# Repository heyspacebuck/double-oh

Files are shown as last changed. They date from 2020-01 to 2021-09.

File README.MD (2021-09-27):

# Double-Oh Battery

## Hardware version 2.7, Firmware version 1.0

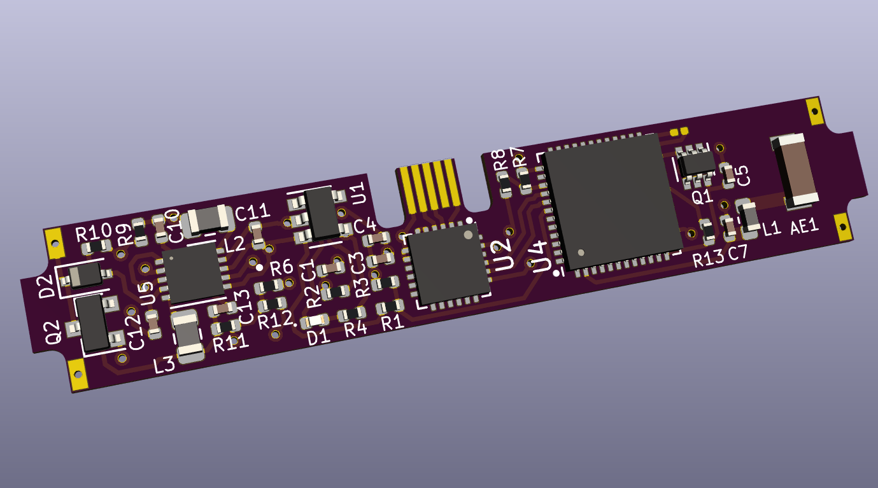
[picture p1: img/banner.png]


This is the spiritual successor to the [SMOL](https://github.com/heyspacebuck/SMOL), a tiny PCB that interrupts battery output to make fun patterns. By designing around a 10mm-by-44mm LiPo cell, I've been able to add Wi-Fi connectivity, a USB connection for charging and programming, and a dangerous (but intriguing!) overvoltage mode.

The star of the show is the ESP32-PICO-D4, a 7mm-by-7mm powerhouse. It handles the wireless networking and various GPIOs.

Hardware developed in KiCad 5.1; firmware built in the Arduino IDE. Licensed/Licenced with the [CERN OHL](https://www.ohwr.org/project/cernohl/wikis/home). Documentation covered by [Creative Commons Attribution (CC-BY) 4.0](https://creativecommons.org/licenses/by/4.0/).

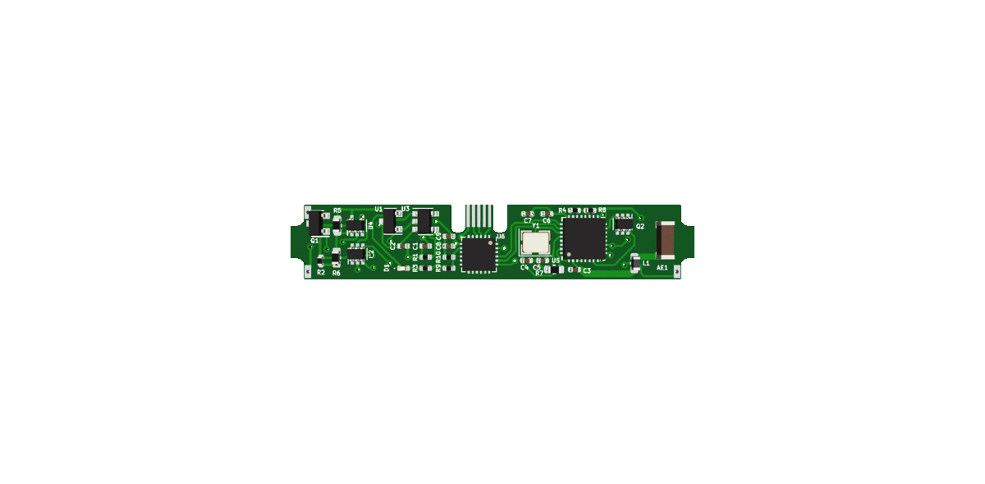
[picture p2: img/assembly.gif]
Small assembly animation


## Assembly, setup, installation

Bill of materials is [here](bom.md). An interactive HTML BOM is [here](/hardware/bom/ibom.html). Assembly and initial setup is covered [here](setup.md).

## Schematic

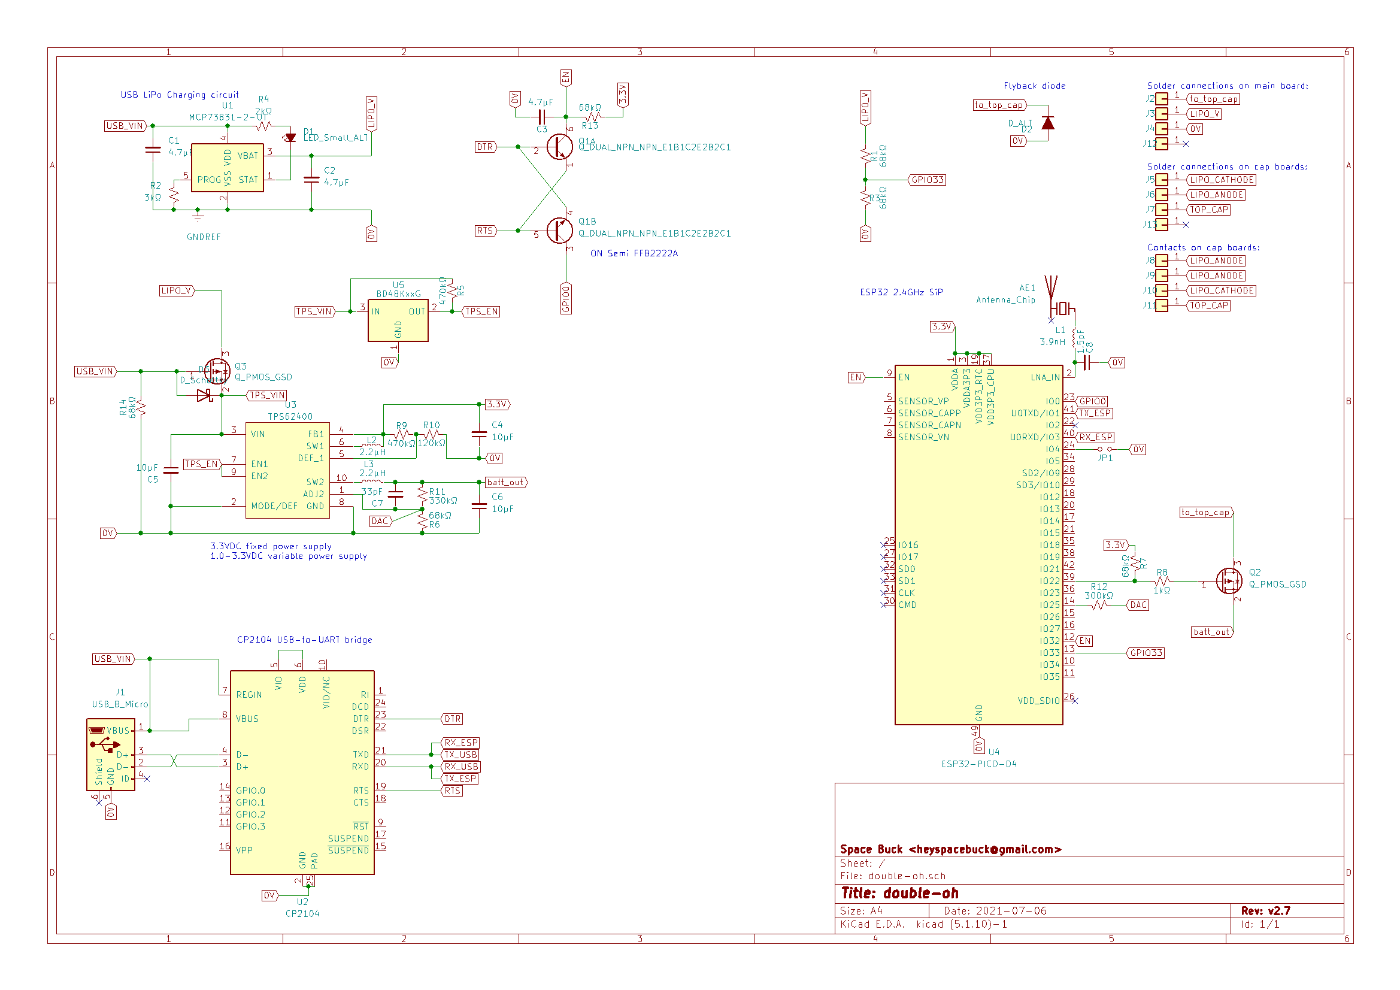
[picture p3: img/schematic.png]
schematic


[A pdf version is also available.](/img/schematic.pdf)

## To do:

* Add pictures to [setup/assembly instructions](setup.md)
* Improve the user interface
* Generate renders



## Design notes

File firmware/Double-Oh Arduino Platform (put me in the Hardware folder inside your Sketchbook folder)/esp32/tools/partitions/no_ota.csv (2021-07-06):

# Name | Type | SubType | Offset | Size | Flags
nvs | data | nvs | 0x9000 | 0x5000
otadata | data | ota | 0xe000 | 0x2000
app0 | app | ota_0 | 0x10000 | 0x200000
spiffs | data | spiffs | 0x210000 | 0x1F0000

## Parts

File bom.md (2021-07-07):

# Bill of Materials
## Valid as of Hardware version 2.7

See also: [interactive HTML BOM](/hardware/bom/ibom.html)

| |References |Value |Footprint |Quantity|Notes |
|---|---|---|---|---|---|
|1 |C1, C2, C3 |4.7μF |0402 (1005 Metric)  |2 | |
|2 |C4, C5, C6 |10μF |0402 (1005 Metric)  |3 | |
|3 |C7 |33pF |0402 (1005 Metric)  |1 | |
|4 |C8 |1.5pF |0402 (1005 Metric)  |1 | |
|5 |R1, R3, R6, R7, R13, R14|68kΩ |0402 (1005 Metric)  |6 | |
|6 |R2 |3kΩ |0402 (1005 Metric)  |1 | |
|7 |R4 |2kΩ |0402 (1005 Metric)  |1 | |
|8 |R5, R9 |470kΩ |0402 (1005 Metric)  |1 | |
|9 |R8 |1kΩ |0402 (1005 Metric)  |1 | |
|10 |R10 |120kΩ |0402 (1005 Metric)  |1 | |
|11 |R11 |330kΩ |0402 (1005 Metric)  |1 | |
|12 |R12 |300kΩ |0402 (1005 Metric)  |1 | |
|13 |L1 |3.9nH |0603 (1608 Metric)  |1 | |
|14 |L2, L3 |2.2μH |0806 (2016 Metric)  |2 |Should be rated for at least 800 mA|
|15 |D1 |LED Blue |0402 (1005 Metric)  |1 | |
|16 |D2, D3 |Schottky Diode |0402 (1005 Metric)  |2 | |
|17 |U1 |MCP73831-2-OT  |SOT-23-5 |1 |USB Li-ion charging controller |
|18 |U2 |CP2104 |QFN-24 4x4mm P0.5mm |1 |USB-to-UART bridge |
|19 |U3 |TPS62400 |VSON-10 3x3mm P0.5mm|1 |Dual-output voltage regulator |
|20 |U4 |ESP32-PICO-D4  |QFN-48 7x7mm P0.5mm |1 |The brains of the operation |
|21 |U5 |BD48K34G |SOT-23 |1 |Low-battery power supervisor; on back of board  |
|22 |AE1 |AMCA31 |1206 (3216 Metric)  |1 |2.4 GHz chip antenna |
|23 |Q1 |BC847BS |SOT-363 (SC-88) |1 |Dual NPN transistors |
|24 |Q2, Q3 |NTS4101P |SOT-323 (SC-70) |2 |P-Channel MOSFET |

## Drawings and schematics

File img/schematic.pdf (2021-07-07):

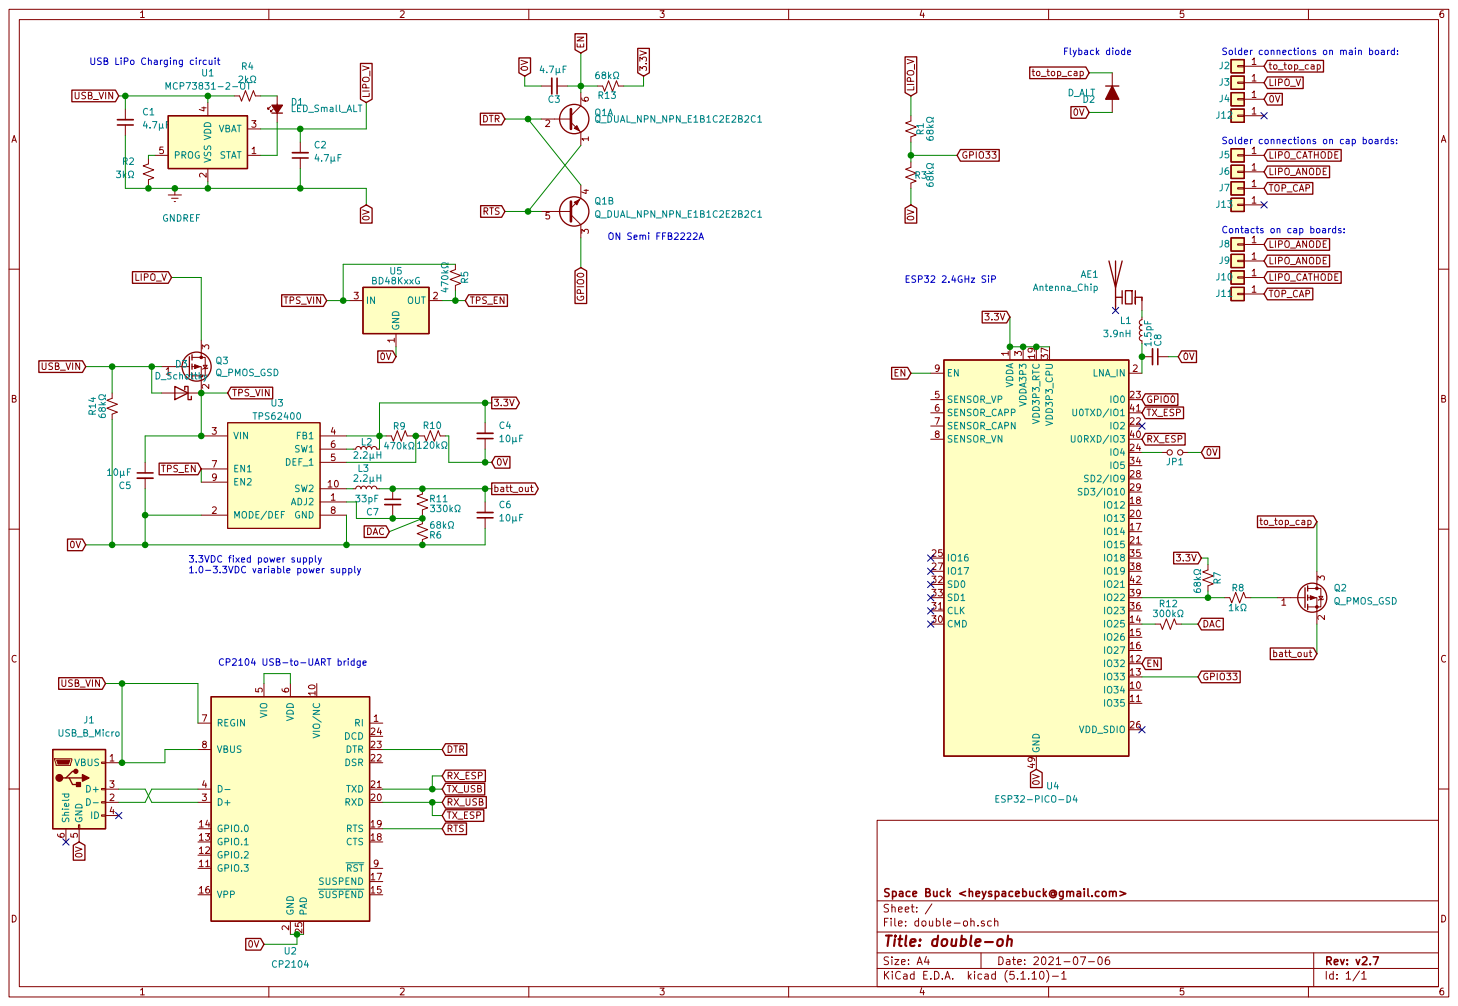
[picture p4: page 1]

USB LiPo Charging circuit

Contacts on cap boards:

CP2104 USB-to-UART bridge

2 RXD 20 TXD 21 DSR 22 DTR 23 DCD 24 PAD 25 D+ 3 D- 4 VIO

File: double-oh.sch Sheet: / Space Buck <heyspacebuck@gmail.com>

Id: 1/1 Title: double-oh

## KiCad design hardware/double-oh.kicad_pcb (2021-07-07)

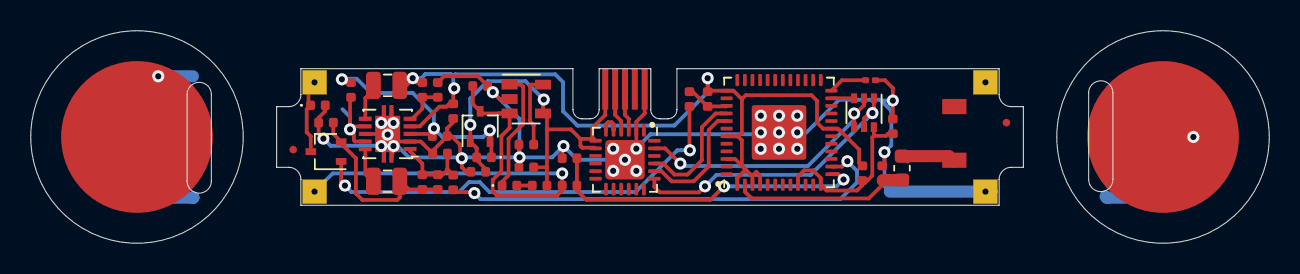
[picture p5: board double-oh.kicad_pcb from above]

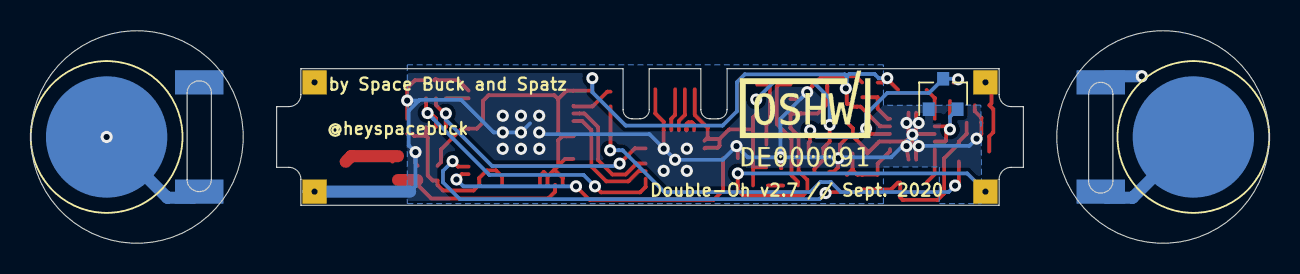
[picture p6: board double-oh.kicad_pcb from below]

Board: 2 copper layers, 81.6 x 14.0 mm, 51 parts (7 on the bottom side), 34 nets.

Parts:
AE1: Antenna_Chip; AMCA31
C1, C2, C3: 4.7μF; C_0402_1005Metric
C4, C5, C6: 10μF; C_0402_1005Metric
C7: 33pF; C_0402_1005Metric
C8: 1.5pF; C_0402_1005Metric
D1: LED_Small_ALT; LED_0402_1005Metric
D2: D_ALT; D_0402_1005Metric
D3: D_Schottky; D_0402_1005Metric
J1: USB_B_Micro; microusb_PCB_socket
J2, J3, J4, J12: Conn_01x01; main_board_solder_mount
J5, J6, J7, J13: Conn_01x01; cap_board_solder_mount
J8, J11: Conn_01x01; cap_contact
J9, J10: Conn_01x01; lipo_contact
JP1: Jumper_NO_Small; R_0201_0603Metric
L1: 3.9nH; L_0603_1608Metric
L2, L3: 2.2μH; L_0806_2016Metric
Q1: Q_DUAL_NPN_NPN_E1B1C2E2B2C1; SOT-363_SC-70-6
Q2, Q3: Q_PMOS_GSD; SOT-323_SC-70
R1, R3, R6, R7, R13, R14: 68kΩ; R_0402_1005Metric
R2: 3kΩ; R_0402_1005Metric
R4: 2kΩ; R_0402_1005Metric
R5, R9: 470kΩ; R_0402_1005Metric
R8: 1kΩ; R_0402_1005Metric
R10: 120kΩ; R_0402_1005Metric
R11: 330kΩ; R_0402_1005Metric
R12: 300kΩ; R_0402_1005Metric
U1: MCP73831-2-OT; SOT-23-5
U2: CP2104; QFN-24-1EP_4x4mm_P0.5mm_EP2.6x2.6mm
U3: TPS62400; VSON-10-1EP_3x3mm_P0.5mm_EP1.65x2.4mm
U4: ESP32-PICO-D4; QFN-48-1EP_7x7mm_P0.5mm_EP3.6x3.6mm
U5: BD48KxxG; SOT-23

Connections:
0V: C1.1, C2.1, C3.2, C4.1, C5.2, C6.1, C8.1, D2.2, J1.5, J4.1, JP1.1, R2.1, R3.2, R6.2, R10.1, R14.1, U1.2, U2.2, U2.25, U3.2, U3.8, U3.11, U4.49, U5.1
3.3V: C4.2, L2.2, R7.1, R9.1, R13.1, U3.4, U4.1, U4.3, U4.4, U4.19, U4.37, U4.43, U4.46
DAC: C7.2, R6.1, R11.2, R12.1, U3.1
DTR: Q1.2, Q1.4, U2.23
EN: C3.1, Q1.6, R13.2, U4.9, U4.12
GPIO0: Q1.3, U4.23
GPIO33: R1.2, R3.1, U4.13
LIPO_ANODE: J6.1, J8.1, J9.1
LIPO_CATHODE: J5.1, J10.1
LIPO_V: C2.2, J3.1, Q3.3, R1.1, U1.3
unnamed: AE1.1, L1.1
unnamed: C8.2, L1.2, U4.2
unnamed: D1.1, U1.1
unnamed: D1.2, R4.2
unnamed: J1.2, U2.4
unnamed: J1.3, U2.3
unnamed: JP1.2, U4.24
unnamed: L2.1, U3.6
unnamed: L3.1, U3.10
unnamed: Q2.1, R8.2
unnamed: R2.2, U1.5
unnamed: R7.2, R8.1, U4.39
unnamed: R9.2, R10.2, U3.5
unnamed: R12.2, U4.14
unnamed: U2.5, U2.6
RTS: Q1.1, Q1.5, U2.19
RX_ESP: U2.21, U4.40
RX_USB: U2.20, U4.41
TOP_CAP: J7.1, J11.1
TPS_EN: R5.2, U3.7, U3.9, U5.2
TPS_VIN: C5.1, D3.1, Q3.2, R5.1, U3.3, U5.3
USB_VIN: C1.2, D3.2, J1.1, Q3.1, R4.1, R14.2, U1.4, U2.7, U2.8
batt_out: C6.2, C7.1, L3.2, Q2.2, R11.1
to_top_cap: D2.1, J2.1, Q2.3

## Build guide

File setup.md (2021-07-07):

# Double-Oh Battery Assembly and Setup

## Hardware version 2.7, Firmware version 1.0



## Main PCB: Top side assembly

Parts used:
- 35 SMD components (see the [BOM](bom.md))
- Main PCB

All but one of the Double-Oh components are placed on the top side of the PCB. When this side is assembled, we can run the device off USB power and install the Double-Oh firmware. The [interactive BOM](/hardware/bom/ibom.html) makes placing the components a lot easier.

## Firmware installation

Tools used:
- Micro-USB cable
- Arduino IDE
- Multimeter (optional)

Now that the top side of the PCB is assembled, the Double-Oh firmware can be installed. Plug in the micro-USB cable and do a quick "smoke test," that is, make sure none of your components are overheating. If everything feels okay, proceed to the Arduino IDE.

If you haven't already, configure the Arduino IDE to work with ESP32 boards. In the "Preferences" window, add the following URL to the "Additional Boards Manager URLs" section: `https://dl.espressif.com/dl/package_esp32_index.json`. Go to `Tools > Board > Boards Manager` and install the "ESP32 by Espressif Systems" boards. A more thorough tutorial [is available here](https://randomnerdtutorials.com/installing-the-esp32-board-in-arduino-ide-windows-instructions/).

To select the Double-Oh board in the Arduino IDE, take the folder `/firmware/Double-Oh Arduino Platform` out of this repo and copy it into your Arduino sketchbook's "Hardware" folder. The folder's new location should be `{your Arduino sketchbook directory}/Hardware/Double-Oh Arduino Platform`. Restart the Arduino IDE. Now, you should be able to select the Double-Oh board under `Tools > Board > Double-Oh > Double-Oh`. **ALTERNATELY:** you can use the "ESP32 Dev Module" from Espressif's boards. If you do this ***make sure PSRAM is disabled!*** As of writing this (July 2021), enabling PSRAM will cause an endless kernel panic reboot cycle, effectively bricking the ESP32.

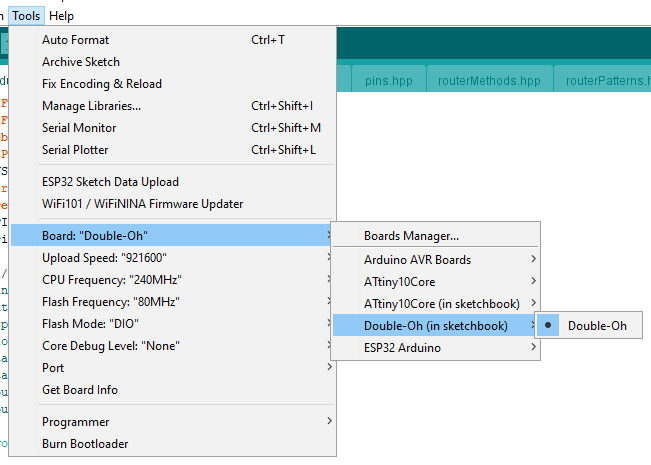
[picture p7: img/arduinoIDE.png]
Screenshot of the Arduino IDE


Open the Double-Oh firmware sketch, located at `/firmware/firmware.ino`. Check that the ESP32 shows up under `Tools > Port` and select it. Upload the file system image by clicking `Tools > ESP32 Sketch Data Upload`. Then upload the firmware with the normal "Upload" button.

**Troubleshooting:** I've encountered several possible errors at this stage, mostly stemming from bad soldering on U2, U3, and U4. If the USB device is not recognized by your computer, that's probably an issue with U2, the USB-to-UART bridge IC. Check that U3 is putting out at least 3.0 volts to power the ESP32; you can do this by probing the locations shown here:

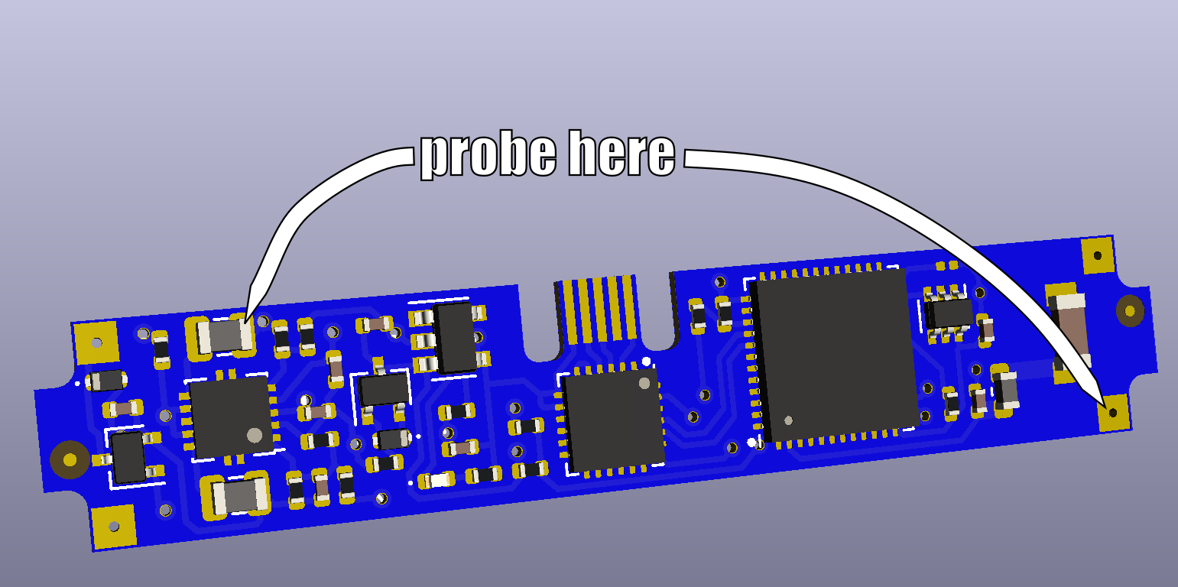
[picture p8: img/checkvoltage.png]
Showing which two points to probe for voltage measurements


If you receive a "Timed out waiting for packet header" message, that typically means either U3 or U4 is soldered incorrectly; often, I have found the ESP32 is not fully soldered to the pads. If you receive an "Incorrect packet header" message, it could mean that the RTS signal is too noisy; you can try increasing the capacitance of C3, the capacitor next to the dual-NPN transistor package.

## Network Testing

When the firmware is first uploaded, the board should start broadcasting its own Wi-Fi network called "double-oh". Connect to the Wi-Fi network and navigate to `http://doubleoh.local` . You should see a simple HTML page with Double-Oh network settings that can be customized.

## Finishing assembly

Parts used:
- U5 (the only component on the bottom of the PCB)
- Cathode (red) PCB
- Anode (black) PCB
- Something to keep the battery in place--a short length of stiff wire, or a [battery terminal spring](https://www.digikey.com/en/products/detail/keystone-electronics/242/7561622), or an [EMI shield finger](https://www.digikey.com/en/products/detail/harwin-inc/S7081-42R/3131061)

Solder part U5, the SOT-23 voltage supervisor, on the bottom side of the PCB. This enables the device to run off a 10440 Li-ion cell.

Take the anode (black) PCB and solder a spring or wire or something to the inner face (the side with a smaller circle on it). This is the part of assembly that I really haven't solved yet. A stiff wire works well, most of the time. Sometimes a single 1.5mm spring suffices; sometimes I have to solder a second 1.5mm spring onto the cathode (red) PCB as well. It's a bit of a mess.

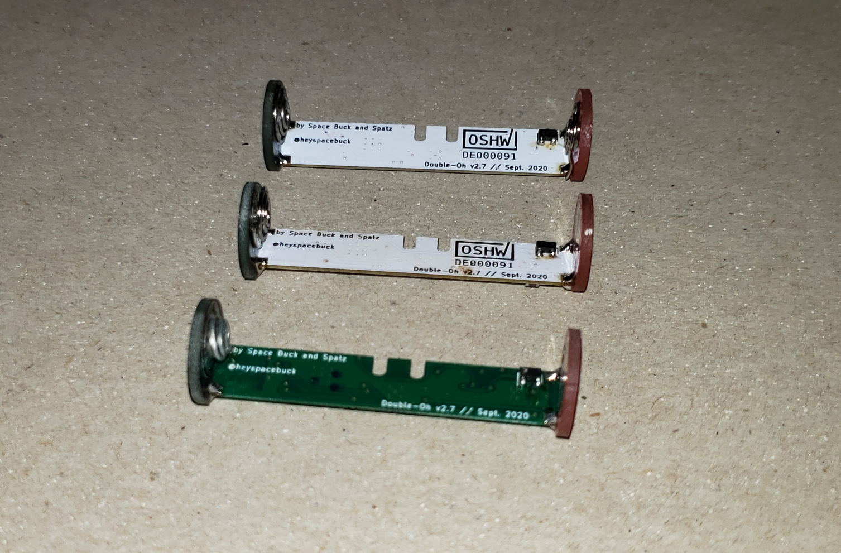
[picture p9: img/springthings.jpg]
Different boards with different spring options


Carefully line up the main PCB in the slot of the anode (black) PCB; the antenna should be close to the black PCB and facing outward. Tack-solder one joint and check the boards for alignment. When the main board and anode board are aligned, . Then do the same with the cathode (red) PCB.

## Battery testing

Parts used:
- 10440 Li-ion cell

Install the Li-ion cell inside the Double-Oh and check again for the "double-oh" Wi-Fi network.

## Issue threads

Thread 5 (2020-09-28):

Silk over vias

silardg, 2020-09-28:
First of all, big fan!

I noticed that the silk (example U2) is over a VIA, which won't look good when manufactured.

heyspacebuck, 2020-09-29:
Thank you for your attention to detail! I have noticed this as well, but until now I had considered it just a minor nuisance. The image at the top of the readme is *very* outdated, since then I have removed all the references from the top of the board; the only remaining silks are on the back of the board and I think they are all legible despite the presence of vias. Again, thanks for writing!

Closed 2020-09-29.

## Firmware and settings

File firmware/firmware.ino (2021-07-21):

#include <WiFi.h>
#include <WiFiClient.h>
#include <WebServer.h>
#include <ESPmDNS.h>
#include <DNSServer.h>
#include <Wire.h>
#include <Preferences.h>
#include <SPIFFS.h>
#include <driver/dac.h>

// From the /include/ folder (the order they're included in here matters!)
#include "pins.hpp"
#include "battery.hpp"
#include "eepromInit.hpp"
#include "globals.hpp"
#include "startEeprom.hpp"
#include "station.hpp"
#include "routerMethods.hpp"
#include "routerPatterns.hpp"

void setup(void) {
  // Set the FET output HIGH (i.e. turn output off)
  ledcSetup(0, 1000, 8);
  ledcAttachPin(OUTPUT_PIN, 0);
  ledcWrite(0, 255);

  // Begin serial link at 115200 baud
  Serial.begin(115200);

  // Check if the factory-reset pads are shorted:
  // Set factory-reset pin to input_pullup
  pinMode(FACTORY_RESET_PIN, INPUT_PULLUP);
  bool factoryReset = false;
  if (!digitalRead(FACTORY_RESET_PIN)) {
    factoryReset = true;
    Serial.println("Factory Reset");
  } else {
    Serial.println("No factory reset");
  }

  // Set DAC voltage test for GPIO 25 (DAC channel 1)
  // Approx 12.126 mV per bit
  dac_output_enable(DAC_CHANNEL_1);
  setBatteryLevel(1.50);
//  dac_output_voltage(DAC_CHANNEL_1, 128); // 2.60 V
//  dac_output_voltage(DAC_CHANNEL_1, 160); // 2.21 V
//  dac_output_voltage(DAC_CHANNEL_1, 180); // 1.97 V
//  dac_output_voltage(DAC_CHANNEL_1, 200); // 1.73 V
//  dac_output_voltage(DAC_CHANNEL_1, 210); // 1.60 V
//  dac_output_voltage(DAC_CHANNEL_1, 220); // 1.49 V
//  dac_output_voltage(DAC_CHANNEL_1, 230); // 1.36 V
//  dac_output_voltage(DAC_CHANNEL_1, 240); // 1.24 V
//  dac_output_voltage(DAC_CHANNEL_1, 255); // 1.06 V

  // Turn on file system
  SPIFFS.begin();

  // Turn on EEPROM, read data, perform a factory reset if the factory-reset pins are shorted
  startEEPROM(factoryReset);

  // If byte 0 is 0x00, set up a soft access point; else set up station
  if (eeprom.wifiType == 0x00) {
    Serial.println("Starting Soft AP");
    startSoftAP();
    // startSoftAP(eeprom.deviceName, dnsServer, DNS_PORT);
  } else {
    Serial.println("Connecting to Wi-Fi");
    // startStation(eeprom, dnsServer, DNS_PORT);
    startStation();
  }


  // On a GET request to /, serve the control panel
  server.on("/", HTTP_GET, handleRoot);

  // On POST request to /settings, change the Wi-Fi configuration
  server.on("/settings", HTTP_POST, handleSettingsPost);

  // On POST request to /power, change the output voltage
  server.on("/power", HTTP_POST, handlePowerPost);

  // On POST request to /reset, reboot the ESP
  server.on("/reset", HTTP_POST, handleResetPost);
  
  // On POST request to /runpattern, update the pattern being run on the battery
  server.on("/runpattern", HTTP_POST, handlePatternPost);

  // On GET requests to .js files, serve the .js files
  server.on("/configure.js", HTTP_GET, []() {
    handleJS("/configure.js");
  });
  server.on("/network.js", HTTP_GET, []() {
    handleJS("/network.js");
  });
  server.on("/battery.js", HTTP_GET, []() {
    handleJS("/battery.js");
  });
  server.on("/pattern.js", HTTP_GET, []() {
    handleJS("/pattern.js");
  });
  server.on("/patternparams.js", HTTP_GET, []() {
    handleJS("/patternparams.js");
  });

  // Serve favicon
  server.on("/favicon.ico", HTTP_GET, handleFavicon);

  // On any other type of request, serve the control panel
  // server.onNotFound(handleRoot);
  server.onNotFound(handleNotFound);

  server.begin();
  Serial.println("HTTP server started");
  
}

void loop(void) {
  // Check battery level and shut down if it's too low
  float battLevel = getBatteryLevel();
  if (battLevel < 3.4) {
    sigmaDeltaWrite(0, 255);
    ESP.deepSleep(0);
    delay(10000);
  }

  // Get whatever DNS requests have piled up
  dnsServer.processNextRequest();
  server.handleClient();
  // If more than 50 milliseconds have elapsed, update the PWM value
  currTime = millis();
  if (currTime - prevTime > 50) {
    motorIntensity = pattern(currTime/1000.0, prevTime/1000.0, motorIntensity);
    ledcWrite(0, motorIntensity);
    Serial.println(motorIntensity);
    prevTime = currTime;
  }
}

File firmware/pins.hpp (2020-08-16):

#ifndef PINS_HPP
#define PINS_HPP

// Hardware pins
#define OUTPUT_PIN 22
#define FACTORY_RESET_PIN 4
#define DAC_PIN 25
#define ADC_PIN 33

#endif

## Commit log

2020-01-04 Repo initialized without submodules
    [double-oh-B_Cu.gbr, double-oh-B_Mask.gbr, double-oh-B_Paste.gbr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]
2020-01-05 Update i2c net names
    [double-oh.kicad_pcb, double-oh.sch]
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2020-01-07 Added a factory-reset pad to hardware
    [double-oh.kicad_pcb, double-oh.sch]
2020-01-07 Updated factory reset hardware to work with factory reset firmware
    [double-oh.kicad_pcb, double-oh.sch]
2020-01-07 Silly mistake; used wrong numbering for factory reset pins
    [main.cpp]
2020-01-07 Fixed crystal layout and routing
    [double-oh.kicad_pcb, double-oh.sch]
2020-01-07 Update main board gerbers
    [double-oh-B_Cu.gbr, double-oh-B_Mask.gbr, double-oh-B_Paste.gbr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]
2020-01-07 Update crystal caps
    [double-oh.kicad_pcb, double-oh.sch]
2020-01-07 Increased text size for legibility
    [double-oh-B_Cu.gbr, double-oh-B_Mask.gbr, double-oh-B_Paste.gbr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]
2020-01-07 Cleaned up Factory-Reset code and also software-reset code
    [main.cpp]
2020-01-09 Working on a version that, y'know, would actually work
    [double-oh.kicad_pcb, double-oh.sch]
2020-01-09 Updated silkscreen for legibility
    [double-oh-B_Cu.gbr, double-oh-B_Mask.gbr, double-oh-B_SilkS.gbr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]
2020-01-09 Renamed footprints to use the correct library name
    [double-oh.sch]
2020-01-10 Added pull-up and pull-down resistors that enable downloading new programs
    [double-oh.kicad_pcb, double-oh.sch]
2020-01-12 Proof-of-concept that the ESP32 would fit on the proscribed space
    [double-oh.kicad_pcb, double-oh.sch]
2020-01-13 Cleaned up power-side routing and placement
    [double-oh.kicad_pcb, double-oh.sch]
2020-01-13 Fixed flyback diode orientation, will reposition power components later
    [double-oh.kicad_pcb, double-oh.sch]
2020-01-14 Added a filter cap to the EN line
    [double-oh.kicad_pcb, double-oh.sch]
2020-01-14 Cleaned up part layout
    [double-oh.kicad_pcb]
2020-01-15 Update to a more viable inductor package size
    [double-oh.kicad_pcb, double-oh.sch]
2020-01-15 Update diode to more viable package
    [double-oh.kicad_pcb, double-oh.sch]
2020-01-15 Minor touchups
    [double-oh.kicad_pcb]
2020-01-15 Laid out power components more cleanly
    [double-oh.kicad_pcb, double-oh.sch]
2020-01-16 Moved vias off of pads
    [double-oh.kicad_pcb]
2020-01-16 Thermal management
    [double-oh.kicad_pcb]
2020-01-16 More routing changes
    [double-oh.kicad_pcb]
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2020-01-23 Up to v2.1 of design. No more digital potentiometer! Added credits for Spatz.
    [double-oh.kicad_pcb, double-oh.sch]
2020-01-23 Remove mentions of old repo name
    [double-oh.kicad_pcb, double-oh.sch]
2020-01-23 Update schematic to reflect correct DAC range
    [double-oh.kicad_pcb, double-oh.sch]
2020-01-24 Now powering CP2104 from USB instead of battery; added voltage monitoring
    [double-oh.kicad_pcb, double-oh.sch]
2020-01-24 Re-added model of antenna
    [double-oh.kicad_pcb]
2020-01-24 Removed rogue dot that remained on silkscreen from Digital Potentiometer
    [double-oh.kicad_pcb]
2020-01-24 Update readme and gerbers
    [double-oh-B_Cu.gbr, double-oh-B_Mask.gbr, double-oh-B_SilkS.gbr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]
2020-01-24 Added MOSFET to switch between USB and battery power when plugged in
    [double-oh.kicad_pcb, double-oh.sch]
2020-01-24 Connected battery readout pin to an ADC
    [double-oh.kicad_pcb, double-oh.sch]
2020-01-24 Update gerbers
    [double-oh-B_Cu.gbr, double-oh-B_Mask.gbr, double-oh-B_SilkS.gbr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]
2020-01-24 Updated footprints and values to match what's available at Digikey.de
    [double-oh.kicad_pcb, double-oh.sch]
2020-01-27 Reverted to 0805 inductor size
    [double-oh-B_Cu.gbr, double-oh-B_Mask.gbr, double-oh-B_SilkS.gbr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]
2020-02-04 Small thermal relief added for buck converter
    [double-oh.kicad_pcb]
2020-02-05 Moved references off board
    [double-oh.kicad_pcb]
2020-02-11 Improved copper pour for ground plane (by Spatz)
    [double-oh.kicad_pcb]
2020-02-14 Trying to figure out what's wrong with this code
    [main.cpp]
2020-02-17 I think I messed up a git filter/smudge somewhere...
    [double-oh.sch]
2020-03-01 Trying a different buck converter IC
    [double-oh.kicad_pcb, double-oh.sch]
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2020-03-02 Working on TPS62400 routing
    [double-oh.kicad_pcb]
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2020-03-15 Removed 3.3V connection to ESP32 pin 26
    [double-oh.kicad_pcb, double-oh.sch]
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2020-07-18 Getting back into it!
    [double-oh.sch]
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2020-07-20 Added a panelized version that can be made by most fab houses
    [panelized-B_Cu.gbr, panelized-B_Mask.gbr, panelized-B_SilkS.gbr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]
2020-07-25 Moved from platformio to arduino because it's less buggy
    [firmware.ino, pins.hpp]
2020-07-30 Updated factory-reset jumper to not use GPIO16, which is reserved
    [double-oh.kicad_pcb, double-oh.sch]
2020-07-30 Fixed stencil and 3d appearance of jumper
    [double-oh.kicad_pcb]
2020-08-01 Changed DAC resistors to be more 'normal' values
    [double-oh.sch]
2020-08-01 Corrected the output pin code (now using sigma-delta) and added some experiments with voltage output
    [firmware.ino]
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2020-08-01 Changed battery-voltage-reading circuit, upped hardware version number
    [double-oh.kicad_pcb, double-oh.sch]
2020-08-02 Updated panel gerber to v2.6
    [panelized-B_Cu.gbr, panelized-B_Mask.gbr, panelized-B_SilkS.gbr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]
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2020-08-06 Updated DAC resistor value
    [double-oh.sch]
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2020-08-07 Bigger pads for chip antenna
    [double-oh.kicad_pcb]
2020-08-07 Update panel and gerbers for larger antenna pads
    [panelized-B_Cu.gbr, panelized-B_Mask.gbr, panelized-B_SilkS.gbr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]
2020-08-09 Rerouted for more thermal vias under buck converter
    [double-oh.kicad_pcb]
2020-08-16 Update DAC pin for battery level control
    [double-oh.kicad_pcb, double-oh.sch]
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2020-08-24 Hardware update with additional safety feature
    [double-oh.kicad_pcb, double-oh.sch]
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2020-09-09 Implemented patterns for vibration output
    [firmware.ino, routerPatterns.hpp]
2020-09-11 Corrected use of voltage supervisor
    [double-oh.kicad_pcb, double-oh.sch]
2020-09-11 Added pull-up resistor for open-drain supervisor
    [double-oh.kicad_pcb, double-oh.sch]
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2020-09-14 Update board to v2.7
    [double-oh.kicad_pcb, double-oh.sch]
2020-09-14 Update gerbers to 2.7
    [double-oh.kicad_pcb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]
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2020-09-28 Add open hardware logo, switch inductor to 0806 size
    [double-oh.kicad_pcb, double-oh.sch]
2020-09-30 Minor tweaks to inductor placement
    [double-oh.kicad_pcb]
2020-09-30 Added 'single buzz' option
    [routerPatterns.hpp]
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2021-07-06 Added ridiculous Arduino Boards Manager hack
    [no_ota.csv]
2021-07-07 Clean up schematic, instructions, and BOM
    [double-oh.kicad_pcb, double-oh.sch]
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

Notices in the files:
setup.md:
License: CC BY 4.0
